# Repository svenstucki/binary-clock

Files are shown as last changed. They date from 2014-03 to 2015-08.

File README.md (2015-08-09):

Binary Clock
============

This repo contains the source files for my self made binary clock. It uses a TI
BQ32000 real-time clock chip for time keeping, a TI TLC5928 LED driver for the
LEDs and an Atmel AtTiny24A microcontroller to control it.

The pcb/ folder contains the schemtaic and board layout (made with EAGLE). The
firmware and source code for the Atmel microcontroller can be found in the code/
folder.

The v1 board layout contains some errors. The footprint for the LDO is wrong
and connects +3V3 to GND. Also I forgot to add a decoupling capacitor for the
RTC. You can work around this by isolating the big tab of the LDO from GND, the
RTC functions without decoupling. Version 2 fixes those errors.

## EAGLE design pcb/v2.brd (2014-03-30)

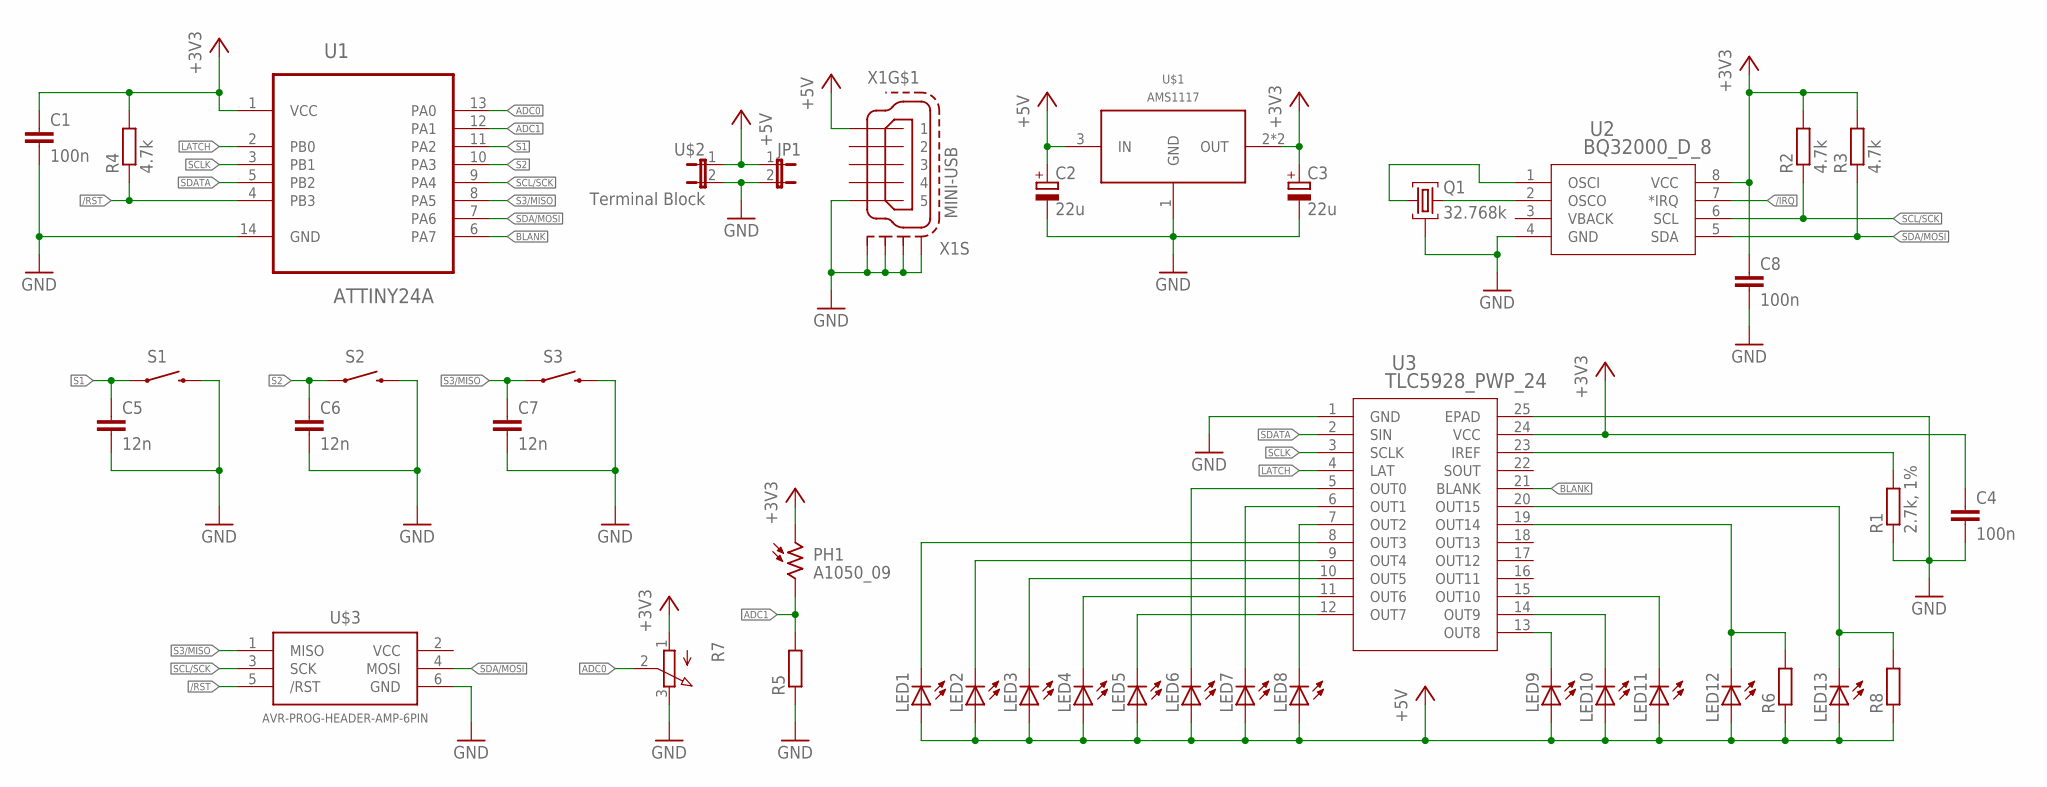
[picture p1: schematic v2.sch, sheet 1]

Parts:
C1, C4, C8: 100n; C0603
C2, C3: 22u; 153CLV-0505
C5, C6, C7: 12n; C0603
JP1: JP1E; JP1
LED1, LED2, LED3, LED4, LED5, LED6, LED7, LED8, LED9, LED10, LED11, LED12, LED13: LEDCHIP-LED0603; CHIP-LED0603
PH1: A1050_09; T0-46-A10XX
Q1: 32.768k; TC38
R1: 2.7k, 1%; R1206
R2, R3, R4: 4.7k; R0603
R5, R6, R8: R-EU_R0603; R0603
R7: 3RP/1610N
S1, S2, S3: SWITCH-MOMENTARY-2PTH; TACTILE-PTH
U1: ATTINY24A; SOIC127P600X175-14N
U2: BQ32000_D_8; D8
U3: TLC5928_PWP_24; PWP24_4P87X2P4
U$1: AMS1117; DCY4
U$2: Terminal Block; BASTLI_SCREW_TERMINAL_SMALL
U$3: AVR-PROG-HEADER-AMP-6PIN; AMP-TMM-1-0-06
X1: MINI-USB; 32005-201

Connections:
+3V3: C1.1, C3.+, C4.1, C8.1, PH1.1, R2.2, R3.2, R4.2, R7.1 (A), U1.1 (VCC), U2.8 (VCC), U3.24 (VCC), U$1.2 (OUT), U$1.4 (OUT)
+5V: C2.+, JP1.1, LED1.A, LED2.A, LED3.A, LED4.A, LED5.A, LED6.A, LED7.A, LED8.A, LED9.A, LED10.A, LED11.A, LED12.A, LED13.A, R6.1, R8.1, U$1.3 (IN), U$2.1, X1.1
/IRQ: U2.7 (*IRQ)
/RST: R4.1, U1.4 (PB3), U$3.5 (/RST)
ADC0: R7.2 (S), U1.13 (PA0)
ADC1: PH1.2, R5.2, U1.12 (PA1)
BLANK: U1.6 (PA7), U3.21 (BLANK)
GND: C1.2, C2.-, C3.-, C4.2, C5.2, C6.2, C7.2, C8.2, JP1.2, Q1.1 (2), R1.1, R5.1, R7.3 (E), S1.3 (2), S2.3 (2), S3.3 (2), U1.14 (GND), U2.4 (GND), U3.1 (GND), U3.25 (EPAD), U$1.1 (GND), U$2.2, U$3.6 (GND), X1.5, X1.M1 (S1), X1.M2 (S2), X1.M3 (S3), X1.M4 (S4); also elsewhere on the board
LATCH: U1.2 (PB0), U3.4 (LAT)
unnamed: LED1.C, U3.8 (OUT3)
unnamed: LED2.C, U3.9 (OUT4)
unnamed: LED3.C, U3.10 (OUT5)
unnamed: LED4.C, U3.11 (OUT6)
unnamed: LED5.C, U3.12 (OUT7)
unnamed: R1.2, U3.23 (IREF)
unnamed: LED6.C, U3.5 (OUT0)
unnamed: LED7.C, U3.6 (OUT1)
unnamed: LED8.C, U3.7 (OUT2)
unnamed: LED9.C, U3.13 (OUT8)
unnamed: LED10.C, U3.14 (OUT9)
unnamed: LED11.C, U3.15 (OUT10)
unnamed: LED12.C, R6.2, U3.19 (OUT14)
unnamed: LED13.C, R8.2, U3.20 (OUT15)
unnamed: Q1.3, U2.2 (OSCO)
unnamed: Q1.2 (1), U2.1 (OSCI)
S1: C5.1, S1.1, U1.11 (PA2)
S2: C6.1, S2.1, U1.10 (PA3)
S3/MISO: C7.1, S3.1, U1.8 (PA5), U$3.1 (MISO)
SCL/SCK: R2.1, U1.9 (PA4), U2.6 (SCL), U$3.3 (SCK)
SCLK: U1.3 (PB1), U3.3 (SCLK)
SDA/MOSI: R3.1, U1.7 (PA6), U2.5 (SDA), U$3.4 (MOSI)
SDATA: U1.5 (PB2), U3.2 (SIN)
VBACK: U2.3 (VBACK)

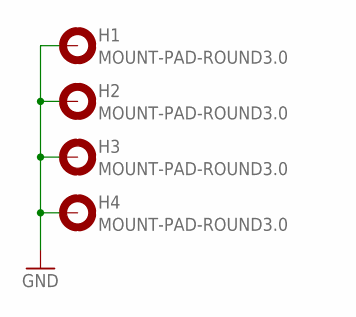
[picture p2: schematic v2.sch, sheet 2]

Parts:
H1, H2, H3, H4: MOUNT-PAD-ROUND3.0; 3,0-PAD

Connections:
GND: H1.B3,0, H2.B3,0, H3.B3,0, H4.B3,0; also elsewhere on the board

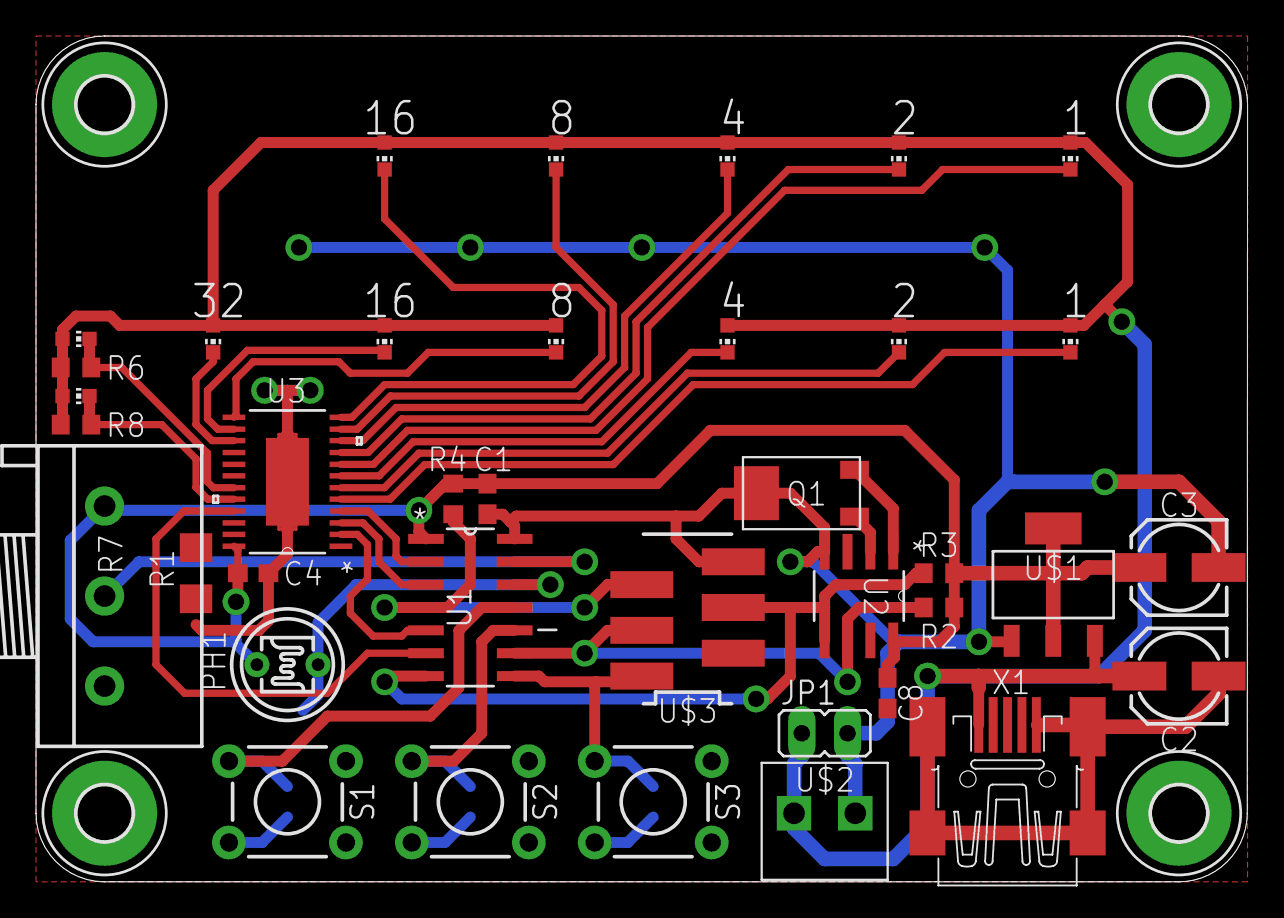
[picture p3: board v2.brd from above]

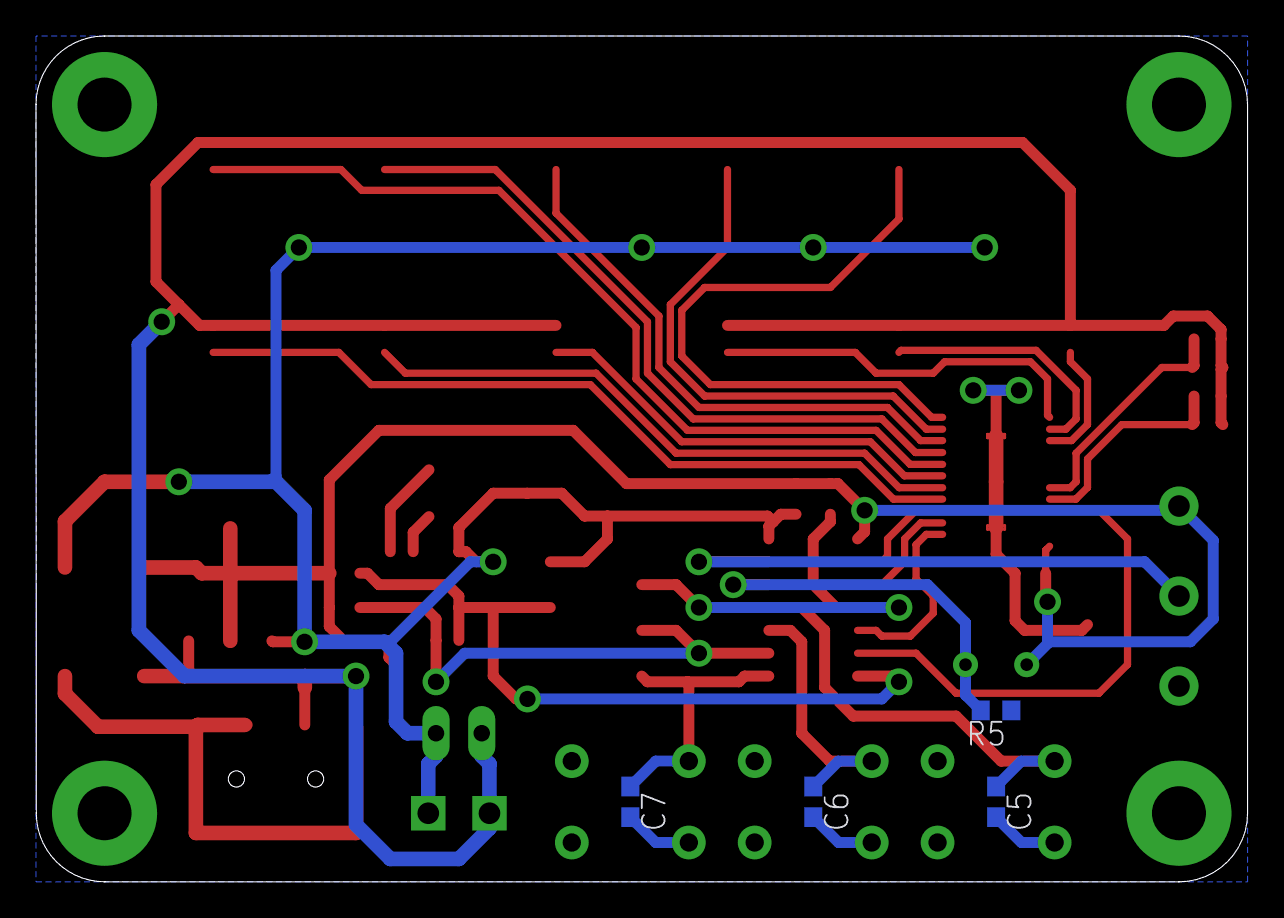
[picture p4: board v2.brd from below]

Board: 2 copper layers, 67.3 x 47.0 mm, 46 parts (4 on the bottom side), 31 nets.

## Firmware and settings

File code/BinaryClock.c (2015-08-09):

/*
 * BinaryClock.c
 *
 * Created: 13.03.2014 15:29:36
 *  Author: Sven Stucki
 */


#include <avr/io.h>
#include <avr/interrupt.h>
#include <inttypes.h>

#include <util/delay.h>

#include "USI_TWI_Master.h"


/* this macro reorders the bits of a uint16_t so they correspond to the order of the LEDs on the board */
#define LED_ORDER(x)	( ((x) & 0xE0) >> 5 | ((x) & 0x1F) << 3 | ((x) & 0xFF00) )


/* application state */

/* 0 - normal, 1 - set hour, 2 - set minute */
uint8_t mode = 0;

/* current time*/
uint8_t time_h = 0, time_m = 0;

uint8_t tick_odd = 0;


/* application logic forward declaration */
void s1();
void s2();
void s3();
void tick();


uint16_t led_state = 0x0000;

/* send new LED state to LED driver */
void set_leds(uint16_t in) {
	unsigned int i;
	
	/* save new state in global */
	led_state = in;
	
	/* make sure latch is low */
	PORTB &= ~(1 << PB0);
	
	for (i = 0; i < 16; i++) {
		/* set clock to low */
		PORTB &= ~(1 << PB1);
		
		/* send bit */
		if (in & 0x8000) {
			PORTB |= (1 << PB2);
		} else {
			PORTB &= ~(1 << PB2);
		}
		
		/* set clock to high */
		PORTB |= (1 << PB1);
		
		/* move to next bit */
		in <<= 1;
	}
	
	/* send latch pulse */
	PORTB |= (1 << PB0);
	PORTB &= ~(1 << PB0);
}


/* interrupt handling */

uint8_t btns_prev;

ISR(PCINT0_vect) {
	uint8_t btns = PINA ^ btns_prev;
	btns_prev = PINA;
	
	if ((PINA & (1 << PA2)) == 0 && (btns & (1 << PA2)) != 0) {
		/* S1 pressed */
		s1();
	}
	if ((PINA & (1 << PA3)) == 0 && (btns & (1 << PA3)) != 0) {
		/* S2 pressed */
		s2();
	}
	if ((PINA & (1 << PA5)) == 0 && (btns & (1 << PA5)) != 0) {
		/* S3 pressed */
		s3();
	}
}

ISR(TIM1_COMPA_vect) {
	tick();
}

ISR(ADC_vect) {
	OCR0B = ADCH >> 1;
	ADCSRA |= (1 << ADSC);
}


#define RTC_ADDRESS	0xD0

void update_time() {
	unsigned char i2c_buffer[3];
	
	/* select minutes register */
	i2c_buffer[0] = RTC_ADDRESS | 0;	// write
	i2c_buffer[1] = 0x01;
	USI_TWI_Start_Transceiver_With_Data(i2c_buffer, 2);
	
	/* read minute and hour register */
	i2c_buffer[0] = RTC_ADDRESS | 1;	// read
	USI_TWI_Start_Transceiver_With_Data(i2c_buffer, 3);
	
	/* convert BCD digits to number */
	unsigned char minute_bcd = i2c_buffer[1];
	time_m = ((minute_bcd >> 4) & 0x07) * 10 + (minute_bcd & 0x0F);
	unsigned char hour_bcd = i2c_buffer[2];
	time_h = ((hour_bcd >> 4) & 0x03) * 10 + (hour_bcd & 0x0F);
}

void set_time() {
	unsigned char i2c_buffer[5];
	i2c_buffer[0] = RTC_ADDRESS | 0;	// write
	i2c_buffer[1] = 0x00;	// seconds register (followed by minute, then hour)
	i2c_buffer[2] = 0x00;	// set seconds to 0
	
	/* convert minute to BCD */
	i2c_buffer[3] = 0;
	i2c_buffer[3] |= (((time_m / 10) % 10) & 0x07) << 4;
	i2c_buffer[3] |= (time_m % 10) & 0x0F;
	
	/* convert hour to BCD */
	i2c_buffer[4] = 0;
	i2c_buffer[4] |= (((time_h / 10) % 10) & 0x03) << 4;
	i2c_buffer[4] |= (time_h % 10) & 0x0F;
	
	USI_TWI_Start_Transceiver_With_Data(i2c_buffer, 5);
}


int main(void) {
	/* disable /8 system clock prescaler */
	CLKPR = 0x80;
	CLKPR = 0x00;
	
	/* setup port directions */
	DDRA = (1 << DDA7);
	DDRB = (1 << DDB0) | (1 << DDB1) | (1 << DDB2);
	
	/* enable pull-ups for buttons */
	PORTA |= (1 << PA2) | (1 << PA3) | (1 << PA5);
	
	USI_TWI_Master_Initialise();

	/* activate LEDs */
	//PORTA &= ~(1 << PA7);
	
	/* prepare and start timer 0 LED PWM */
	TCCR0A = (1 << COM0B1) | (1 << COM0B0) | (1 << WGM01) | (1 << WGM00);
	TCCR0B = (0 << WGM02) | (0 << CS02) | (0 << CS01) | (1 << CS00);
	OCR0B = 0xA0;
	
	/* prepare and start timer 1 for 2 Hz interrupt */
	TCCR1A = 0x00;
	TCCR1B = (1 << WGM12) | (1 << CS11) | (1 << CS10);	// CTC mode, /64 prescale
	TCCR1C = 0x00;
	OCR1A = 0xF424;		// count to 62500 -> exactly 2 Hz
	TIMSK1 = (1 << OCIE1A);
	
	/* prepare and enable button interrupts */
	btns_prev = PINA;
	PCMSK0 = (1 << PCINT2) | (1 << PCINT3) | (1 << PCINT5);
	GIMSK = 0x10;
	
	/* prepare and start ADC */
	ADMUX = (1 << MUX0);
	ADCSRA = (1 << ADEN) | (1 << ADSC) | (1 << ADIE) | (1 << ADPS2) | (1 << ADPS1) | (1 << ADPS0);
	ADCSRB = (1 << ADLAR);
	
	/* enable global interrupts */
	sei();
	
	while(1);
		return 0;
}


/* application logic */

void s1() {
	mode = (mode + 1) % 3;
}

void s2() {
	if (mode == 1) {
		/* increase hour */
		time_h++;
		if (time_h >= 24) {
			time_h = 0;
		}
	} else if (mode == 2) {
		/* increase minute */
		time_m++;
		if (time_m >= 60) {
			time_m = 0;
			time_h++;
			if (time_h >= 24) {
				time_h = 0;
			}
		}
	}
}

void s3() {
	if (mode == 1) {
		/* decrease hour */
		if (time_h == 0) {
			time_h = 23;
		} else {
			time_h--;
		}
	} else if (mode == 2) {
		/* decrease minute */
		if (time_m == 0) {
			if (time_h == 0) {
				time_h = 23;
			} else {
				time_h--;
			}
			time_m = 59;
		} else {
			time_m--;
		}
	}
}


void tick() {
	tick_odd++;
	
	uint16_t leds = 0;
	if (mode == 0) {
		/* display time */
		update_time();
		leds = LED_ORDER((time_m << 5) | time_h);
	} else if (mode == 1) {
		/* flash hour */
		set_time();
		if (tick_odd % 2 == 0) {
			leds = LED_ORDER(time_m << 5);
		} else {
			leds = LED_ORDER((time_m << 5) | time_h);
		}
		leds |= 0x8000;
	} else if (mode == 2) {
		/* flash minute */
		set_time();
		if (tick_odd % 2 == 0) {
			leds = LED_ORDER(time_h);
		} else {
			leds = LED_ORDER((time_m << 5) | time_h);
		}
		leds |= 0x4000;
	}
	set_leds(leds);
}

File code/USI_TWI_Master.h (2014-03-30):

/*****************************************************************************
*
* Atmel Corporation
*
* File              : USI_TWI_Master.h
* Compiler          : AVRGCC Toolchain version 3.4.2
* Revision          : $Revision: 992 $
* Date              : $Date: 2013-11-07 $
* Updated by        : $Author: Atmel $
*
* Support mail      : avr@atmel.com
*
* Supported devices : All device with USI module can be used.
*                     The example is written for the ATmega169, ATtiny26 and ATtiny2313
*
* AppNote           : AVR310 - Using the USI module as a TWI Master
*
* Description       : This is an implementation of an TWI master using
*                     the USI module as basis. The implementation assumes the AVR to
*                     be the only TWI master in the system and can therefore not be
*                     used in a multi-master system.
* Usage             : Initialize the USI module by calling the USI_TWI_Master_Initialise() 
*                     function. Hence messages/data are transceived on the bus using
*                     the USI_TWI_Start_Transceiver_With_Data() function. If the transceiver
*                     returns with a fail, then use USI_TWI_Get_Status_Info to evaluate the 
*                     couse of the failure.
*
****************************************************************************/
    #include<avr/io.h> 
//********** Defines **********//

// Defines controlling timing limits
//#define TWI_FAST_MODE

#define SYS_CLK   4000.0  // [kHz]

#ifdef TWI_FAST_MODE               // TWI FAST mode timing limits. SCL = 100-400kHz
  #define T2_TWI    ((SYS_CLK *1300) /1000000) +1 // >1,3us
  #define T4_TWI    ((SYS_CLK * 600) /1000000) +1 // >0,6us
  
#else                              // TWI STANDARD mode timing limits. SCL <= 100kHz
  #define T2_TWI    ((SYS_CLK *4700) /1000000) +1 // >4,7us
  #define T4_TWI    ((SYS_CLK *4000) /1000000) +1 // >4,0us
#endif

// Defines controling code generating
//#define PARAM_VERIFICATION
//#define NOISE_TESTING
//#define SIGNAL_VERIFY

//USI_TWI messages and flags and bit masks
//#define SUCCESS   7
//#define MSG       0
/****************************************************************************
  Bit and byte definitions
****************************************************************************/
#define TWI_READ_BIT  0       // Bit position for R/W bit in "address byte".
#define TWI_ADR_BITS  1       // Bit position for LSB of the slave address bits in the init byte.
#define TWI_NACK_BIT  0       // Bit position for (N)ACK bit.

#define USI_TWI_NO_DATA             0x00  // Transmission buffer is empty
#define USI_TWI_DATA_OUT_OF_BOUND   0x01  // Transmission buffer is outside SRAM space
#define USI_TWI_UE_START_CON        0x02  // Unexpected Start Condition
#define USI_TWI_UE_STOP_CON         0x03  // Unexpected Stop Condition
#define USI_TWI_UE_DATA_COL         0x04  // Unexpected Data Collision (arbitration)
#define USI_TWI_NO_ACK_ON_DATA      0x05  // The slave did not acknowledge  all data
#define USI_TWI_NO_ACK_ON_ADDRESS   0x06  // The slave did not acknowledge  the address
#define USI_TWI_MISSING_START_CON   0x07  // Generated Start Condition not detected on bus
#define USI_TWI_MISSING_STOP_CON    0x08  // Generated Stop Condition not detected on bus

// Device dependant defines

#if defined(__AVR_AT90Mega169__) | defined(__AVR_ATmega169PA__) | \
    defined(__AVR_AT90Mega165__) | defined(__AVR_ATmega165__) | \
    defined(__AVR_ATmega325__) | defined(__AVR_ATmega3250__) | \
    defined(__AVR_ATmega645__) | defined(__AVR_ATmega6450__) | \
    defined(__AVR_ATmega329__) | defined(__AVR_ATmega3290__) | \
    defined(__AVR_ATmega649__) | defined(__AVR_ATmega6490__)
    #define DDR_USI             DDRE
    #define PORT_USI            PORTE
    #define PIN_USI             PINE
    #define PORT_USI_SDA        PORTE5
    #define PORT_USI_SCL        PORTE4
    #define PIN_USI_SDA         PINE5
    #define PIN_USI_SCL         PINE4
#endif

#if defined (__AVR_ATtiny24__) | \
	defined (__AVR_ATtiny24A__) | \
	defined (__AVR_ATtiny44__) | \
	defined (__AVR_ATtiny84__)
	#define DDR_USI			DDRA
	#define PORT_USI		PORTA
	#define PIN_USI			PINA
	#define PORT_USI_SDA	PORTA6
	#define PORT_USI_SCL	PORTA4
	#define PIN_USI_SDA		PINA6
	#define PIN_USI_SCL		PINA4
#endif

#if defined(__AVR_ATtiny25__) | defined(__AVR_ATtiny45__) | defined(__AVR_ATtiny85__) | \
    defined(__AVR_AT90Tiny26__) | defined(__AVR_ATtiny26__)
    #define DDR_USI             DDRB
    #define PORT_USI            PORTB
    #define PIN_USI             PINB
    #define PORT_USI_SDA        PORTB0
    #define PORT_USI_SCL        PORTB2
    #define PIN_USI_SDA         PINB0
    #define PIN_USI_SCL         PINB2
#endif

#if defined(__AVR_AT90Tiny2313__) | defined(__AVR_ATtiny2313__)
    #define DDR_USI             DDRB
    #define PORT_USI            PORTB
    #define PIN_USI             PINB
    #define PORT_USI_SDA        PORTB5
    #define PORT_USI_SCL        PORTB7
    #define PIN_USI_SDA         PINB5
    #define PIN_USI_SCL         PINB7
#endif

// General defines
#define TRUE  1
#define FALSE 0

//********** Prototypes **********//

void              USI_TWI_Master_Initialise( void );
 unsigned char USI_TWI_Start_Transceiver_With_Data( unsigned char * , unsigned char );
unsigned char USI_TWI_Get_State_Info( void );

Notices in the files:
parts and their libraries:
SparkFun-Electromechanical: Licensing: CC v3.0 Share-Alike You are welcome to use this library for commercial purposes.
